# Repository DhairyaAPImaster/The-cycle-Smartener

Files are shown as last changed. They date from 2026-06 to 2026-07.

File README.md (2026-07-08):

Cycle smartener banner

# The Cycle Smartener
**(Makes the cycle kindda smart)**
### By Dhairya

## About "The Cycle Smartener"

So the Cycle smartener or TCS for short is basically this device that i designed that can be fitted on top of (almost) any modern cycle. Btw i made this cause i absolutelly love cycling and yeah having such a device would make the whole ride way more fun and interesting.

I plan on integrating TinyML (later) to also integrate AI into it so that it can do stuff like change the song or answer questions from voice commands. Alsoin next versions i plan on adding bluetooth so that one can connect their device - smart phone or something to it. and an sd card slot for one to put a micro sd in it to add music.

Btw it also has a 2.4inch LCD Display  (to displays whatever needs to be displayed).

## Folder Structure

`firmware/` - ESP32 firmware source code (C++)

`src/` - source files for PCB and CAD

`src/FreeCAD/` - mechanical CAD sources (open the .FCStd in FreeCAD)

`src/KiCAD/` - KiCad project files for the PCB

`Production/` - exports and fab outputs (gerbers, BOM, STLs)

`Production/PCB/` - gerbers, BOM, CPL files

`Production/CAD/` - exported STLs for the case

`images/` - screenshots and photos used in this README

## BOM with non PCB parts as well as PCB parts (with links)

Here's the parts list i kept while designing - both PCB parts and non-PCB components. i used the file `Production/BOM with non PCB parts too.csv` as the source.

| Item | Purpose | Qty | Unit Price (USD) | Total (USD) | Link |
| --- | --- | ---: | ---: | ---: | --- |
| Micro SD 16GB | For storage | 1 | $13.07 | $13.07 | [link](https://robu.in/product/sandisk-ultra-micro-sd-16gb-uhs-i-98mbs-r-class-10-memory-card/) |
| 40 Pin 2.54mm Male and Female Pin Headers | For connecting modules | 1 | $1.25 | $1.25 | [link](https://www.amazon.in/Super-Debug-Headers-Arduino-Prototype/dp/B09MZD3RBF) |
| Micro SD Card Reader Module | For storage/songs | 1 | $0.35 | $0.35 | [link](https://robu.in/product/micro-sd-card-module/) |
| 3mm Red LED | Status/Error Indicator | 11 | $0.01 | $0.10 | [link](https://robu.in/product/3mm-red-dip-led-pack-of-50/) |
| 3mm Green LED | Status/OK Indicator | 7 | $0.02 | $0.11 | [link](https://robu.in/product/5mm-green-surface-mount-led-pack-of-50/) |
| Tactile Push Button Switch 6x6 | Buttons | 1 Pack | $0.16 | $0.16 | [link](https://robu.in/product/6x6x5-tactile-push-button-switch/) |
| 10uF 25V Electrolytic Capacitor (Pack of 12) | Decoupling | 1 Pack | $0.83 | $0.83 | [link](https://www.amazon.in/10uF-25V-Electrolytic-Capacitor-Pack/dp/B08X2NSPZN) |
| 0.1µF Ceramic Capacitor (100nF) | Decoupling | 10 | $0.01 | $0.13 | [link](https://robu.in/product/100nf-50v-disc-capacitor/) |
| 150Ω Through-Hole Resistor | LED Current Limiting | 5 | $0.04 | $0.19 | [link](https://robu.in/product/mf25-150r-multicomp-pro-through-hole-resistor-150-ohm-mf25-series-250-mw-%C2%B1-1-axial-leaded-250-v/) |
| 10kΩ Through-Hole Resistor | Pull-up/Pull-down | 5 | $0.03 | $0.13 | [link](https://robu.in/product/mfr-25frf52-10k-yageo-metal-film-resistors-10k%CF%89-250mw-%C2%B1100ppm-%E2%84%83-%C2%B11-plugind2-4xl6-3mm-through-hole-resistors-rohs/) |
| 18650 Single Cell Holder | Battery Holder | 1 | $0.29 | $0.29 | [link](https://robu.in/product/1-x-18650-cell-box/) |
| 3.7V 2500mAh Li-Ion Battery | Power | 1 | $1.58 | $1.58 | [link](https://robocraze.com/products/3-7v-2500mah-18650-li-ion-battery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) |
| AMS1117-3.3V Voltage Regulator | Voltage Regulation | 2 | $0.09 | $0.19 | [link](https://robu.in/product/ams1117-3-3v-1a-sot-223-voltage-regulator-ic-pack-of-5-ics/) |
| TP4056 Type-C Charging Module | Li-Ion Charger | 1 | $0.17 | $0.17 | [link](https://robu.in/product/tp4056-1a-li-ion-battery-charging-board-micro-usb-with-current-protection-type-c-connector/) |
| INMP441 MEMS I2S Microphone Module | Audio Input | 1 | $4.58 | $4.58 | [link](https://www.flyrobo.in/inmp441-mems-high-precision-omnidirectional-microphone-module-i2s-interface-supports-esp32) |
| MAX98357 I2S 3W Class-D Audio Amplifier | Audio Output | 1 | $3.38 | $3.38 | [link](https://www.flyrobo.in/max98357-i2s-3w-class-d-audio-amplifier-module) |
| CP2102 USB to TTL UART Converter | Programming | 1 | $1.18 | $1.18 | [link](https://robu.in/product/cp-2102-6-pin/) |
| Waveshare 2.4" 240×320 LCD Display | User Interface | 1 | $11.09 | $11.09 | [link](https://robu.in/product/waveshare-240x320-general-2-4inch-lcd-display-module-65k-rgb/) |
| ESP32-WROOM-32U Wi-Fi + BLE Module | Main Microcontroller | 1 | $2.81 | $2.81 | [link](https://evelta.com/esp32-wroom-32u-wi-fi-ble-module-4mb-ipex-antenna-connector/?sku=136-ESP32-WROOM-32U-N4) |
| JLCPCB PCB Fabrication + Shipping | Custom PCB Manufacturing | 1 | $18.48 | $18.48 | [link](https://jlcpcb.com/) |
| JLCPCB Tax | Taxes | 1 | $7.40 | $7.40 | [link](https://jlcpcb.com/) |

| **Summary** | | | | |
| --- | --- | ---: | ---: | ---: |
| Electronics Components Total | | | | **$41.61** |
| JLCPCB (PCB + Shipping) | | | | **$18.48** |
| Tax | | | | **$7.40** |
| **Grand Total (USD)** | | | | **$67.49** |

***

## BOM with only PCB parts and no links (got from KiCAD)

<details>
<summary><b>Click to expand Bill of Materials</b></summary>

| Designator | Designation | Quantity | Footprint |
|---|---|---|---|
| C1, C2 | 10µF | 2 | CP_Radial_D5.0mm_P2.50mm |
| C3, C7, C8, C9 | 0.1uF | 4 | C_Disc_D5.0mm_W2.5mm_P5.00mm |
| C4 | 10uF | 1 | C_Disc_D5.0mm_W2.5mm_P5.00mm |
| D1 | GREEN LED | 1 | LED_D5.0mm |
| D2 | RED LED | 1 | LED_D5.0mm |
| J1 | TP4056 Module | 1 | PinHeader_1x02_P2.54mm_Vertical |
| J2 | AudioJack3 | 1 | Jack_3.5mm_CUI_SJ-3523-SMT_Horizontal |
| J3 | SD CARD READER | 1 | PinHeader_1x06_P2.54mm_Horizontal |
| J4 | J5A - INMP441 Left | 1 | PinHeader_1x03_P2.54mm_Vertical |
| J5 | J5B - INMP441 Right | 1 | PinHeader_1x06_P2.54mm_Vertical |
| J6 | UART_HEADER | 1 | PinHeader_1x08_P2.54mm_Vertical |
| J7 | Display connector | 1 | PinHeader_1x08_P2.54mm_Vertical |
| J8 | MAX 98357A_left | 1 | PinHeader_1x02_P2.54mm_Vertical |
| J9 | MAX 98357A_right | 1 | PinHeader_1x07_P2.54mm_Vertical |
| R1 | R | 1 | R_Axial_DIN0207_L6.3mm_D2.5mm_P10.16mm_Horizontal |
| R2 | 10k | 1 | R_Axial_DIN0207_L6.3mm_D2.5mm_P10.16mm_Horizontal |
| R4, R5 | 150 | 2 | R_Axial_DIN0207_L6.3mm_D2.5mm_P10.16mm_Horizontal |
| SW1, SW2 | SW_Push | 2 | SW_PUSH_6mm |
| U1 | ESP32-WROOM-32 | 1 | ESP32-WROOM-32 |
| U2 | AMS1117-3.3 | 1 | SOT-223-3_TabPin2 |

</details>

## How to Replicate

- Step 1 - Basically Just Clone or downlaod this repo from github. U can do this by either going to the code button on this repo page and pressing download Zip or u can clone this Repo Or you can go to the Releases on this repo and download the Zip File there too (the fastest way to download is like just going to code and pressing download Zip Or by cloning the Repo.)

- Step 2 - In the the production folder you will find the CAD and PCB folders.

- Step 3 - The CAD folder contains all the 3d Pritnable files for the case of the keyboard. If you wish to u can make any changes to the design or make your own design and use that instead.

- Step 4 - The PCB folder contains the Gerbers, BOM , and CPL files. These are the files that allow you to get the PCB manufactured from JLCPCB (im using JLCPCB) or any other PCB manufacturer(like PCBway or others).

- Step 5 - Upload the gerbers zip file in JLCPCB "Place order / get instant quote" Page (u will need to sign up to order but can get a quote without signing up)

- Step 6 - Change the colour of the PCB in the options JLC gives (if u use JLC PCB most of the times canging colours does not add any charge acc to what i know)

- Step 7 - Select PCBA if u want JLCPCB to assemble the PCB for you but ngl soldering all components by hand is cheaper and saves u a ton of money and also is pretty fun (im hand soldering all components)

- Step 8 - Upload the CPL and BOM files whe JLCPCB asks u to.

- Step 9 - Recheck the position of all components (i faced no problem with this as all components were in the correct place but i have faced issues with the placement in one of my other projects i made in KiCAD)
- Step 10 - Order the PCB

- Step 11 - if u dont have a 3d printer u can order the 3d model from JLC's JLC3DP but yeah all you have to do now is print the case and assemble the PCB in the case. (note u might have to trim down the spacers just a little)

- Step 12 - Get 8 M2 bolts and 8 heat insterts for it.

- Step 13 - Attatch the heat insrets into the case through the holes made for the hook. each hook has 4 holes for botlts.

- Step 14 - Position the hook from below on the cycles bar and position the case itself above it and then carefully screw in the screws securing the device to your cycle!!!!!!

- DONE!!!!! 

## Images











image (13)
image (12)
image (11)
image (11)
image (10)
image (10)
image (9)
image (9)
image (8)
image (8)
image (7)
image (7)
image (6)
image (6)
image (5)
image (5)
image (4)
image (4)
image (3)
image (3)
image (2)
image (2)
image (1)


## License and Credits

**License -->**
This project is licensed under the MIT License — see the [LICENSE](LICENSE) file for details.

**Credits -->**
***I used the following for making this project***

- ***KiCAD*** - For PCB design
- ***FreeCAD*** - For designing the Case
- **[APX HUB by @Gabouin](https://github.com/Gabouin/APX-USB-HUB)** - Readme template

## Final Notes

**Firmware Note --->  Used a friend help and also used AI (github copilot) too to like help me write a part of it as well ngl I suck at C++ also like used github copilot to like arrange the code in a more readable manner.**

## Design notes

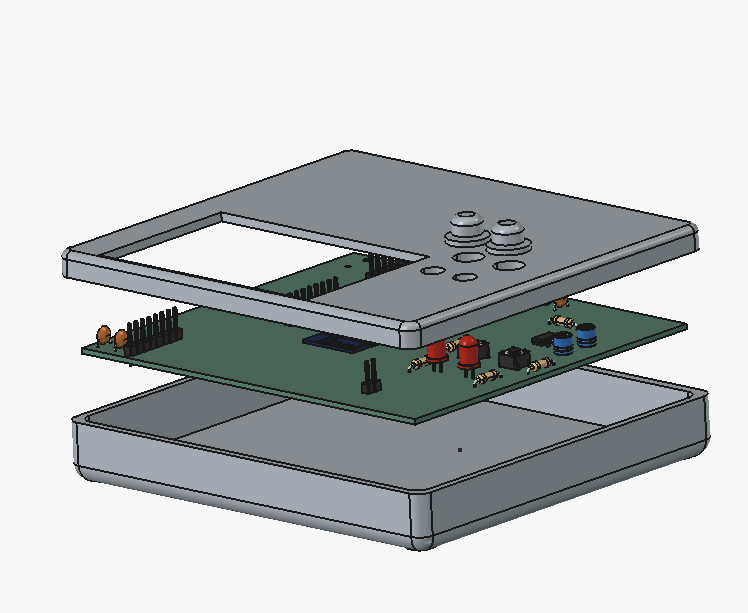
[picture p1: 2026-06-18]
images/Screenshot 2026-06-17 184801.png

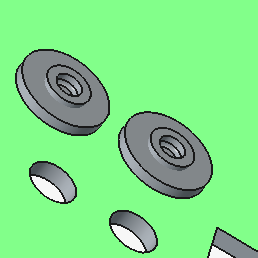
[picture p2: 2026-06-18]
images/Screenshot 2026-06-17 182813.png

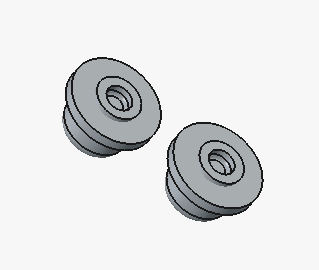
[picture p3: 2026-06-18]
images/Screenshot 2026-06-17 182823.png

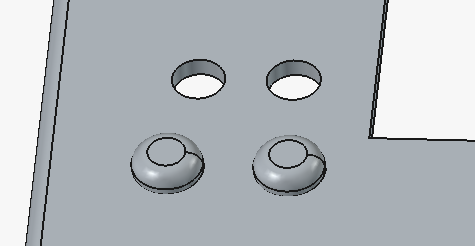
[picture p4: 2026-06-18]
images/Screenshot 2026-06-17 182800.png

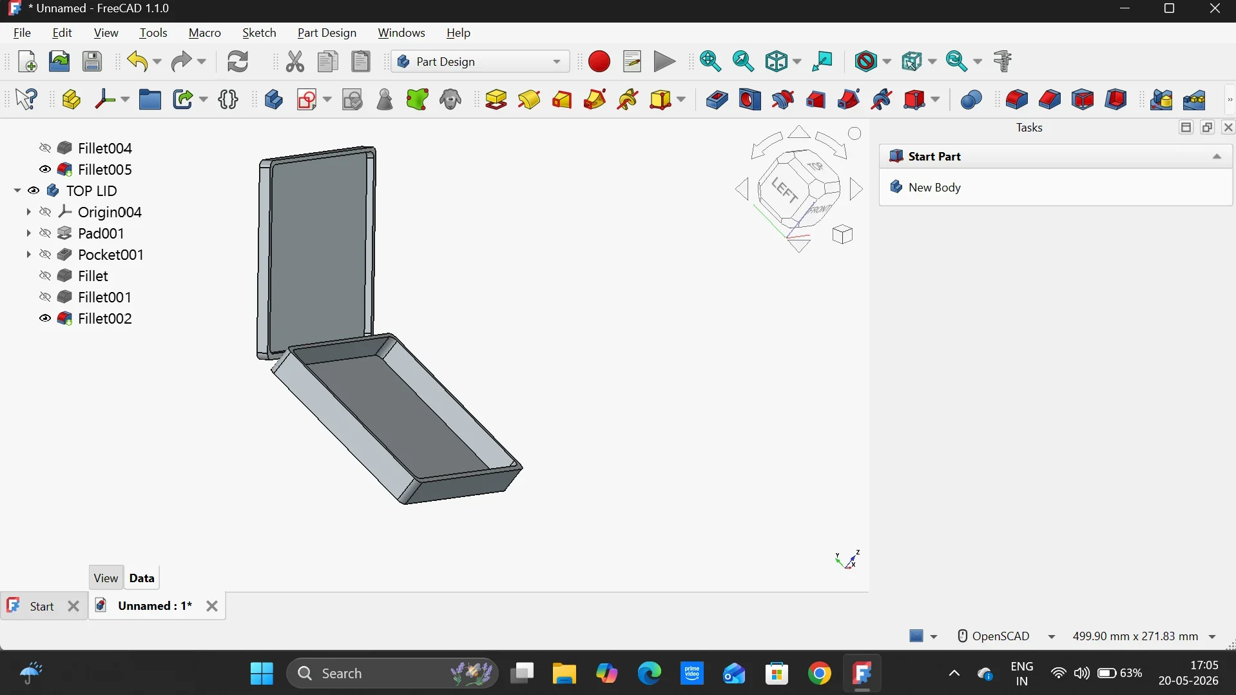
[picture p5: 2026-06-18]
images/image.webp

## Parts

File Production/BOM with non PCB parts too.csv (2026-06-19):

Name | Purpose | Quantity | Total Cost (USD) | Link | Distributor
Micro SD 16GB | For storage | 1 | 11.51 | https://robu.in/product/sandisk-ultra-micro-sd-16gb-uhs-i-98mbs-r-class-10-memory-card/ | Robu.in
40 Pin 2.54mm Male and Female Pin Headers | For connecting modules to the PCB. (btw this one has both male and female headers for almost the same price and umm... its good as i do not have to order both male and female headers separately and its also affordable with free delhivery.) | 1 | 1.78 | https://www.amazon.in/Super-Debug-Headers-Arduino-Prototype/dp/B09MZD3RBF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 | Amazon
Micro SD Card Reader Module | mainly for storage and adding songs | 1 | 0.34 | https://robu.in/product/micro-sd-card-module/ | Robu.in
3mm Red LED | to show that something is wrong in the PCB (robu.in has min order value of 10inr hence the qty is 7) | 7 | 0.11 | https://robu.in/product/3mm-red-dip-led-pack-of-50/ | Robu.in
3mm Green LED | to show that everything works (robu.in has min order value of 10inr hence the qty is 7) | 7 | 0.12 | https://robu.in/product/5mm-green-surface-mount-led-pack-of-50/ | Robu.in
Tactile Push Button Switch 6x6 | For the switches (btw robu.in has min order value of 10inr so instead of buying 10 individual buttons i got the pack of 10 at almost the same price) | 1 | 0.14 | http://robu.in/product/6x6x5-tactile-push-button-switch/ | Robu.in
10uF 25V Electrolytic Capacitor | For decoupling | 1 | 0.83 | https://www.amazon.in/10uF-25V-Electrolytic-Capacitor-Pack/dp/B08X2NSPZN?s=industrial | Amazon
0.1µF Ceramic Capacitor THT | For the decoupling capacitors(robu.in has min order value of 10inr so hence i had to put qty as 10) | 10 | 0.14 | https://robu.in/product/100nf-50v-disc-capacitor/ | Robu.in
150Ω Resistor THT | To resist at 150ohms | 5 | 0.20 | https://robu.in/product/mf25-150r-multicomp-pro-through-hole-resistor-150-ohm-mf25-series-250-mw-%C2%B1-1-axial-leaded-250-v/ | Robu.in
10kΩ Resistor THT | to "resist" the flow of current | 5 | 0.14 | https://robu.in/product/mfr-25frf52-10k-yageo-metal-film-resistors-10k%CF%89-250mw-%C2%B1100ppm-%E2%84%83-%C2%B11-plugind2-4xl6-3mm-through-hole-resistors-rohs/ | Robu.in
18650 single cell holder | To hold the battery | 1 | 0.31 | https://robu.in/product/1-x-18650-cell-box/ | Robu.in
3.7V 2600mAh Li-Ion Battery | to provide power. (1 battery is backup) | 2 | 2.70 | https://robu.in/product/dmegc-inr18650-26e-3-7v-2600mah-li-ion-battery/ | Robu.in
AMS1117 3.3V SOT223 | to regulate the voltage. btw robu.in has a minimum order value of 10inr hence i have to order 2 of these. | 2 | 0.19 | https://robu.in/product/ams1117-3-3v-1a-sot-223-voltage-regulator-ic-pack-of-5-ics/ | Robu.in
TP4056 micro USB charger module | To charge | 1 | 0.17 | https://robu.in/product/tp4056-1a-li-ion-battery-charging-board-micro-usb-with-current-protection-type-c-connector/ | Robu.in
INMP441 Mic Module | for microphone audio | 1 | 4.46 | https://www.flyrobo.in/inmp441-mems-high-precision-omnidirectional-microphone-module-i2s-interface-supports-esp32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 | FlyRobo
MAX98357 I2S 3W CLASS D Audio Amplifier Module | For audio to convert digital signals to analog while amplifying it. | 1 | 3.47 | https://www.flyrobo.in/max98357-i2s-3w-class-d-audio-amplifier-module?tracking=ads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 | FlyRobo
CP2102(6-pin) USB 2.0 to TTL UART serial converter | To program the esp32 wroom32 chip | 1 | 1.20 | http://robu.in/product/cp-2102-6-pin/ | robu.in
2.4inch LCD Display Module | To see | 1 | 10.95 | https://robu.in/product/waveshare-240x320-general-2-4inch-lcd-display-module-65k-rgb/ | Robu.in
ESP32-WROOM-32U Wi-Fi BLE Module | This is basically the brains of this project it shall run every component. | 1 | 3.29 | https://evelta.com/esp32-wroom-32u-wi-fi-ble-module-4mb-ipex-antenna-connector/?sku=136-ESP32-WROOM-32U-N4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 | Evelta

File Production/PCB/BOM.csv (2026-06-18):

Id | Designator | Footprint | Quantity | Designation | Supplier and ref
1 | C1, C2 | CP_Radial_D5.0mm_P2.50mm | 2 | 10µF
2 | C3, C7, C8, C9 | C_Disc_D5.0mm_W2.5mm_P5.00mm | 4 | 0.1uF
3 | C4 | C_Disc_D5.0mm_W2.5mm_P5.00mm | 1 | 10uF
4 | D1 | LED_D5.0mm | 1 | GREEN LED
5 | D2 | LED_D5.0mm | 1 | RED LED
6 | J1 | PinHeader_1x02_P2.54mm_Vertical | 1 | TP4056 Module
7 | J2 | Jack_3.5mm_CUI_SJ-3523-SMT_Horizontal | 1 | AudioJack3
8 | J3 | PinHeader_1x06_P2.54mm_Horizontal | 1 | SD CARD READER
9 | J4 | PinHeader_1x03_P2.54mm_Vertical | 1 | J5A - INMP441 Left
10 | J5 | PinHeader_1x06_P2.54mm_Vertical | 1 | J5B - INMP441 Right
11 | J6 | PinHeader_1x08_P2.54mm_Vertical | 1 | UART_HEADER
12 | J7 | PinHeader_1x08_P2.54mm_Vertical | 1 | Display connector
13 | J8 | PinHeader_1x02_P2.54mm_Vertical | 1 | MAX 98357A_left
14 | J9 | PinHeader_1x07_P2.54mm_Vertical | 1 | MAX 98357A_right
15 | R1 | R_Axial_DIN0207_L6.3mm_D2.5mm_P10.16mm_Horizontal | 1 | R
16 | R2 | R_Axial_DIN0207_L6.3mm_D2.5mm_P10.16mm_Horizontal | 1 | 10k
17 | R4, R5 | R_Axial_DIN0207_L6.3mm_D2.5mm_P10.16mm_Horizontal | 2 | 150
18 | SW1, SW2 | SW_PUSH_6mm | 2 | SW_Push
19 | U1 | ESP32-WROOM-32 | 1 | ESP32-WROOM-32
20 | U2 | SOT-223-3_TabPin2 | 1 | AMS1117-3.3

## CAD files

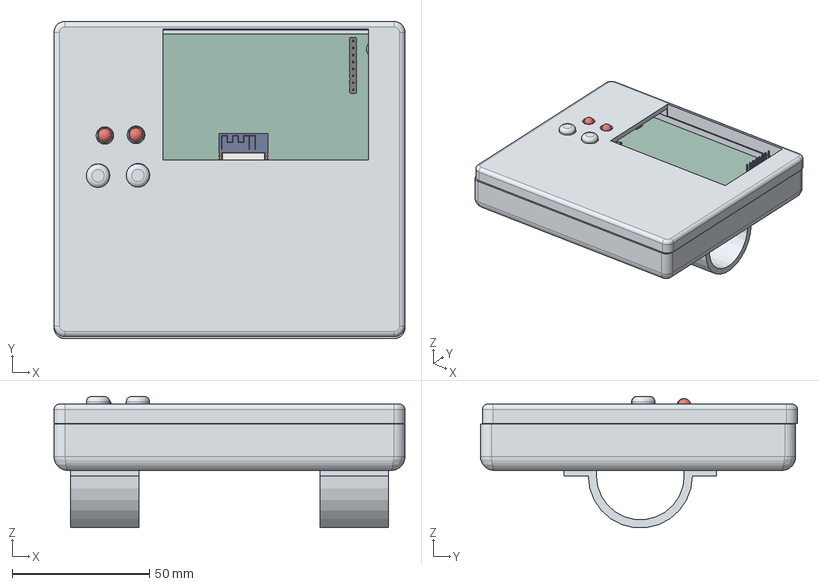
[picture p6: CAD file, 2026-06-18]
Assembly.step
128.0 x 115.7 x 47.9 mm
TOP LID
PCB
C_Disc_D5.0mm_W2.5mm_P5.00mm
PinHeader_1x07_P2.54mm_Vertical
C_Disc_D5.0mm_W2.5mm_P5.00mm001
PinHeader_1x08_P2.54mm_Vertical
PinHeader_1x08_P2.54mm_Vertical001
C_Disc_D5.0mm_W2.5mm_P5.00mm002
ESP32-WROOM-32
R_Axial_DIN0207_L6.3mm_D2.5mm_P10.16mm_Horizontal
C_Disc_D5.0mm_W2.5mm_P5.00mm003
C_Disc_D5.0mm_W2.5mm_P5.00mm004
CP_Radial_D5.0mm_P2.50mm
PinHeader_1x03_P2.54mm_Vertical
R_Axial_DIN0207_L6.3mm_D2.5mm_P10.16mm_Horizontal001
PinHeader_1x02_P2.54mm_Vertical
R_Axial_DIN0207_L6.3mm_D2.5mm_P10.16mm_Horizontal002
R_Axial_DIN0207_L6.3mm_D2.5mm_P10.16mm_Horizontal003
CP_Radial_D5.0mm_P2.50mm001
CP_Radial_D5.0mm_P2.50mm002
LED_D5.0mm
PinHeader_1x06_P2.54mm_Vertical
R_Axial_DIN0207_L6.3mm_D2.5mm_P10.16mm_Horizontal004
SW_PUSH_6mm
C_Disc_D5.0mm_W2.5mm_P5.00mm005
PinHeader_1x02_P2.54mm_Vertical001
LED_D5.0mm001
SW_PUSH_6mm001
SOT-223
PCB wired_PCB
Butons
button caps non slider plate disc
Cycle handle clamp
Cycle handle clamp001

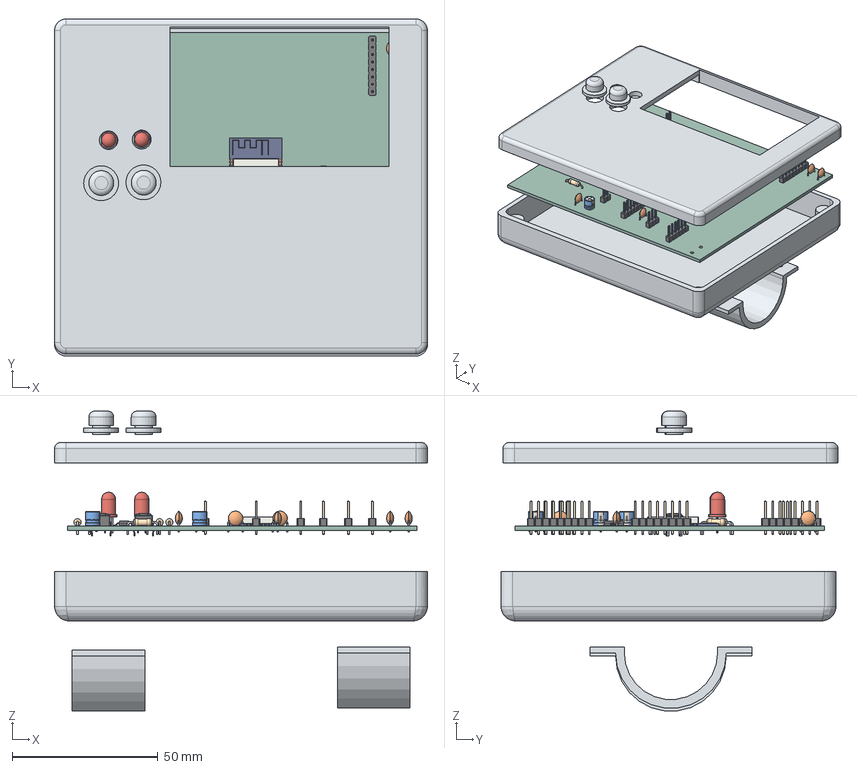
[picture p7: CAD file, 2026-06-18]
Assembly Layered.step
128.0 x 115.7 x 102.9 mm
TOP LID
PCB
C_Disc_D5.0mm_W2.5mm_P5.00mm
PinHeader_1x07_P2.54mm_Vertical
C_Disc_D5.0mm_W2.5mm_P5.00mm001
PinHeader_1x08_P2.54mm_Vertical
PinHeader_1x08_P2.54mm_Vertical001
C_Disc_D5.0mm_W2.5mm_P5.00mm002
ESP32-WROOM-32
R_Axial_DIN0207_L6.3mm_D2.5mm_P10.16mm_Horizontal
C_Disc_D5.0mm_W2.5mm_P5.00mm003
C_Disc_D5.0mm_W2.5mm_P5.00mm004
CP_Radial_D5.0mm_P2.50mm
PinHeader_1x03_P2.54mm_Vertical
R_Axial_DIN0207_L6.3mm_D2.5mm_P10.16mm_Horizontal001
PinHeader_1x02_P2.54mm_Vertical
R_Axial_DIN0207_L6.3mm_D2.5mm_P10.16mm_Horizontal002
R_Axial_DIN0207_L6.3mm_D2.5mm_P10.16mm_Horizontal003
CP_Radial_D5.0mm_P2.50mm001
CP_Radial_D5.0mm_P2.50mm002
LED_D5.0mm
PinHeader_1x06_P2.54mm_Vertical
R_Axial_DIN0207_L6.3mm_D2.5mm_P10.16mm_Horizontal004
SW_PUSH_6mm
C_Disc_D5.0mm_W2.5mm_P5.00mm005
PinHeader_1x02_P2.54mm_Vertical001
LED_D5.0mm001
SW_PUSH_6mm001
SOT-223
PCB wired_PCB
Butons
button caps non slider plate disc
Cycle handle clamp
Cycle handle clamp001

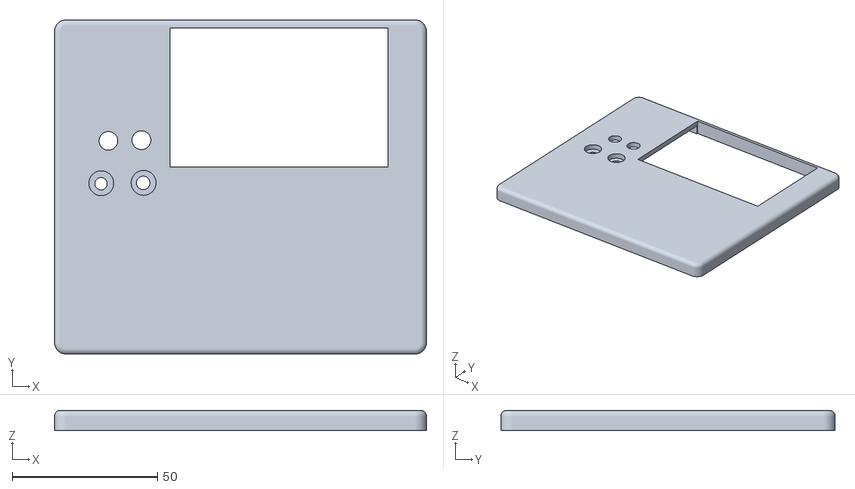
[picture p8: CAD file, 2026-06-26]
all 3d files in .stl format/Top Case.stl
128.0 x 115.0 x 7.00

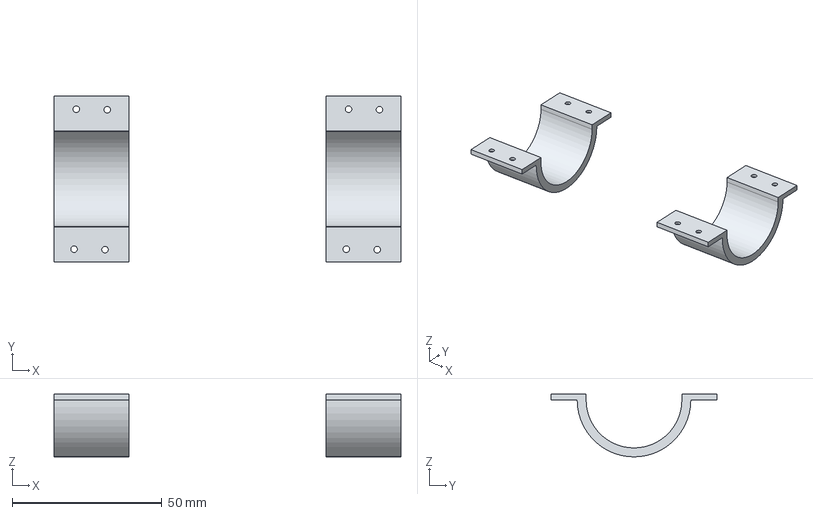
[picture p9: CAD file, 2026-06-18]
Production/CAD/Handle Clamps.step
116.0 x 55.6 x 21.0 mm
Cycle handle clamp
Cycle handle clamp001

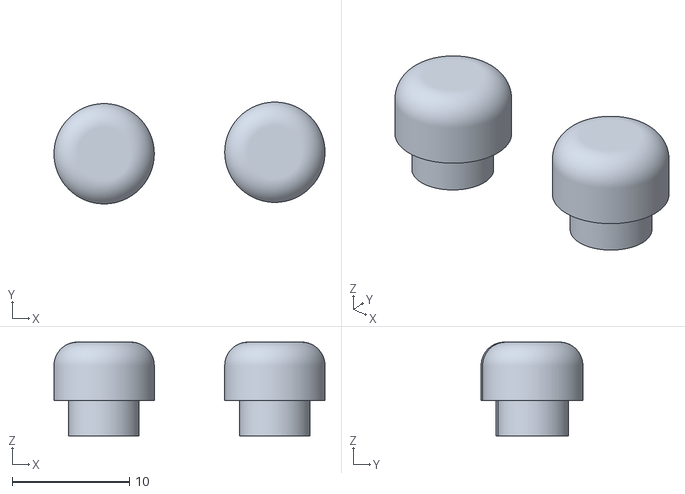
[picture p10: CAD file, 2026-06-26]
all 3d files in .stl format/Buttons.stl
23.1 x 8.68 x 8.00

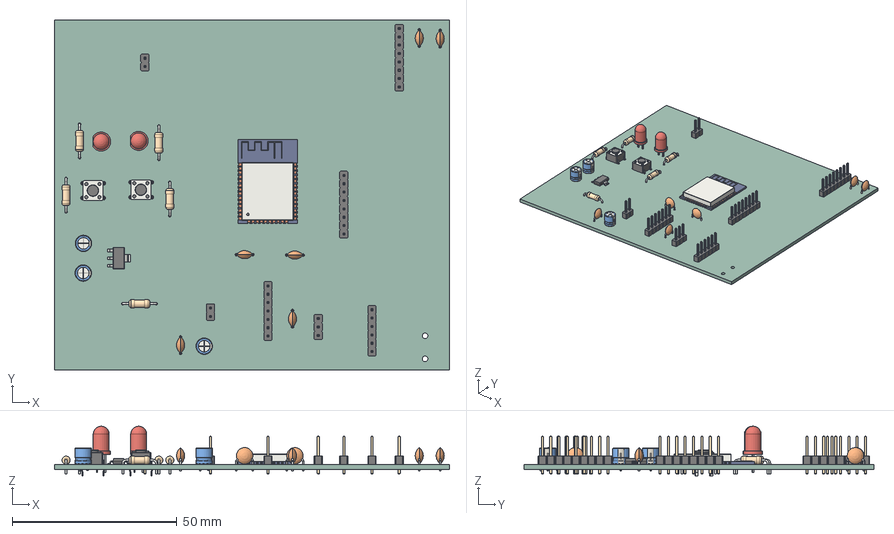
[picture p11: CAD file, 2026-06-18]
PCB 3d Model.step
120.0 x 106.3 x 15.1 mm
C_Disc_D5.0mm_W2.5mm_P5.00mm
PinHeader_1x07_P2.54mm_Vertical
C_Disc_D5.0mm_W2.5mm_P5.00mm001
PinHeader_1x08_P2.54mm_Vertical
PinHeader_1x08_P2.54mm_Vertical001
C_Disc_D5.0mm_W2.5mm_P5.00mm002
ESP32-WROOM-32
R_Axial_DIN0207_L6.3mm_D2.5mm_P10.16mm_Horizontal
C_Disc_D5.0mm_W2.5mm_P5.00mm003
C_Disc_D5.0mm_W2.5mm_P5.00mm004
CP_Radial_D5.0mm_P2.50mm
PinHeader_1x03_P2.54mm_Vertical
R_Axial_DIN0207_L6.3mm_D2.5mm_P10.16mm_Horizontal001
PinHeader_1x02_P2.54mm_Vertical
R_Axial_DIN0207_L6.3mm_D2.5mm_P10.16mm_Horizontal002
R_Axial_DIN0207_L6.3mm_D2.5mm_P10.16mm_Horizontal003
CP_Radial_D5.0mm_P2.50mm001
CP_Radial_D5.0mm_P2.50mm002
LED_D5.0mm
PinHeader_1x06_P2.54mm_Vertical
R_Axial_DIN0207_L6.3mm_D2.5mm_P10.16mm_Horizontal004
SW_PUSH_6mm
C_Disc_D5.0mm_W2.5mm_P5.00mm005
PinHeader_1x02_P2.54mm_Vertical001
LED_D5.0mm001
SW_PUSH_6mm001
SOT-223
PCB wired_PCB

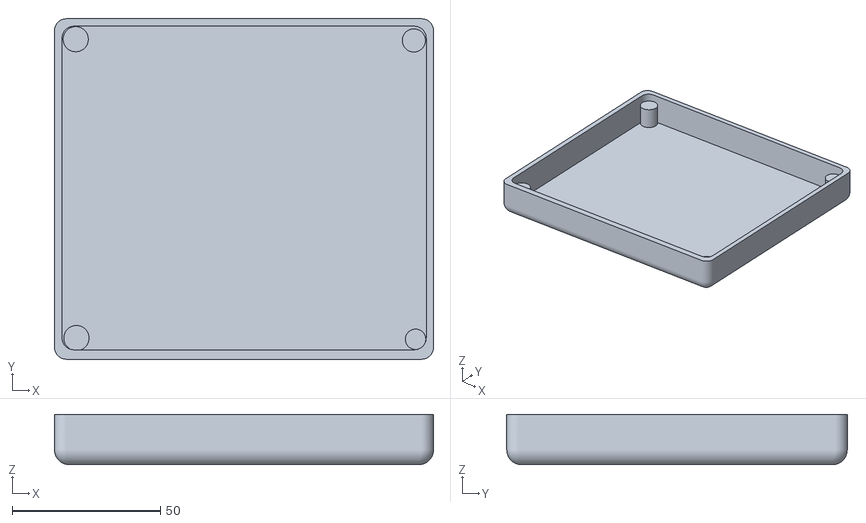
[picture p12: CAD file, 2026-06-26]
all 3d files in .stl format/Bottom Case.stl
128.0 x 115.0 x 17.0

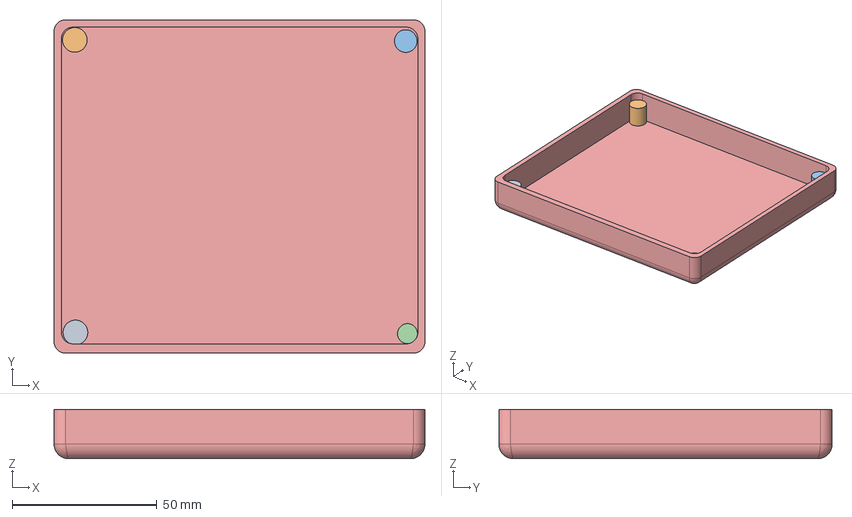
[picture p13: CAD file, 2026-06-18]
Production/CAD/Bottom Case.step
128.0 x 115.0 x 17.0 mm
PCB

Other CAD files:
src/FreeCAD/Case 3d Model.FCStd
Production/CAD/Buttons.step
all 3d files in .stl format/Handle Clamps.stl
Production/CAD/Top Case.step

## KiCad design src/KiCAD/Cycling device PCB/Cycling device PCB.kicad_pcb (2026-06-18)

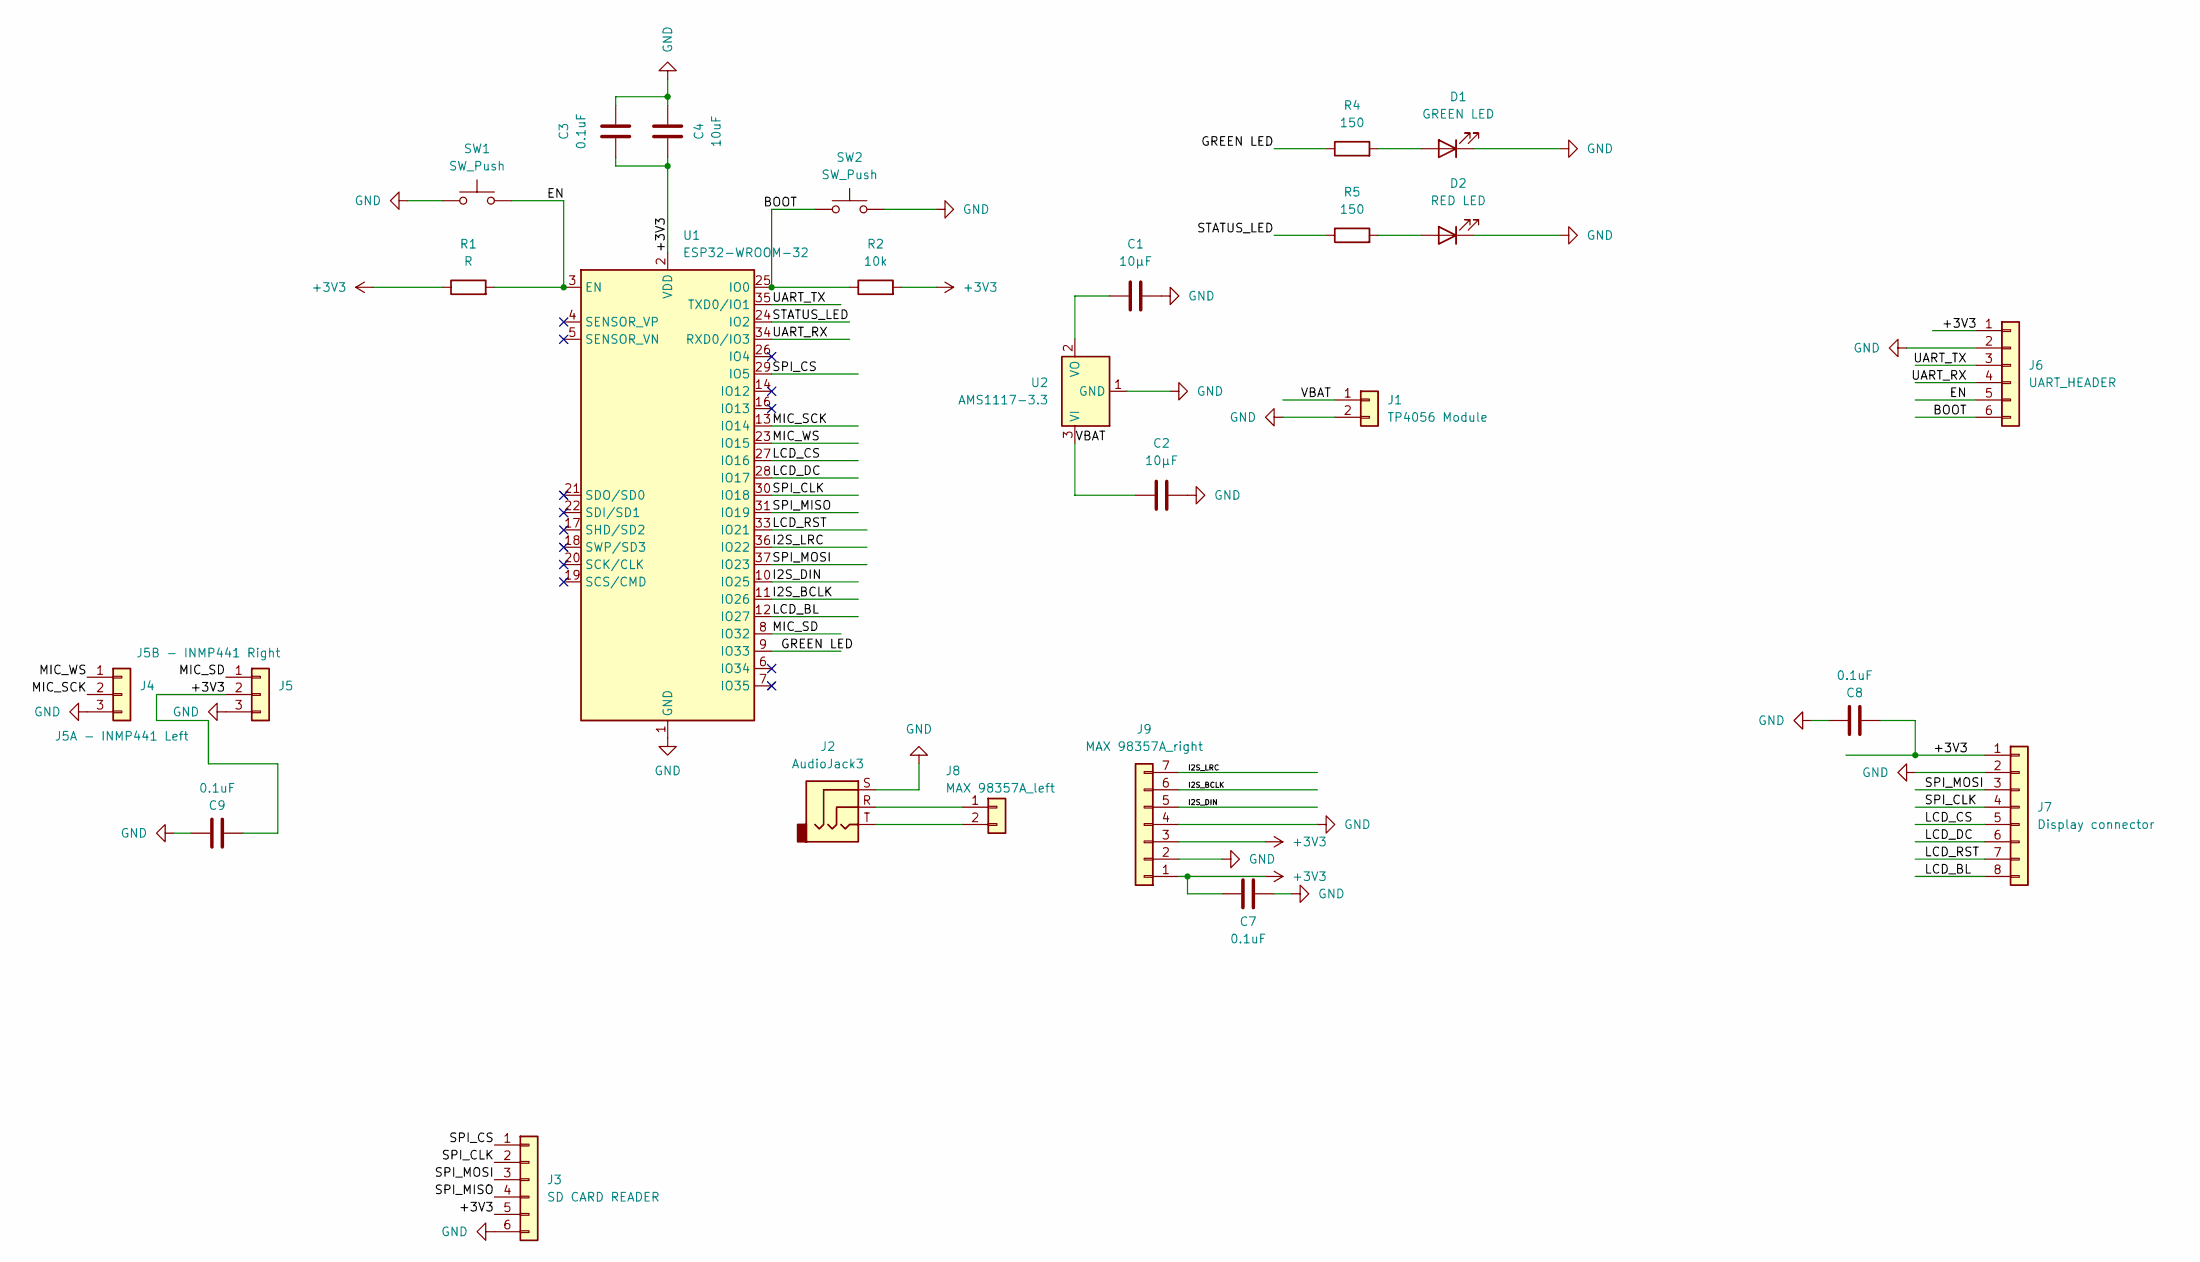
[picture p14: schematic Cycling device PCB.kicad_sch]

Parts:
C1, C2: 10µF; CP_Radial_D5.0mm_P2.50mm
C3, C7, C8, C9: 0.1uF; C_Disc_D5.0mm_W2.5mm_P5.00mm
C4: 10uF; C_Disc_D5.0mm_W2.5mm_P5.00mm
D1: GREEN LED; LED_D5.0mm
D2: RED LED; LED_D5.0mm
J1: TP4056 Module; PinHeader_1x02_P2.54mm_Vertical
J2: AudioJack3; Jack_3.5mm_CUI_SJ-3523-SMT_Horizontal
J3: SD CARD READER; PinHeader_1x06_P2.54mm_Horizontal
J4: J5A - INMP441 Left; PinHeader_1x03_P2.54mm_Vertical
J5: J5B - INMP441 Right; PinHeader_1x06_P2.54mm_Vertical
J6: UART_HEADER; PinHeader_1x08_P2.54mm_Vertical
J7: Display connector; PinHeader_1x08_P2.54mm_Vertical
J8: MAX 98357A_left; PinHeader_1x02_P2.54mm_Vertical
J9: MAX 98357A_right; PinHeader_1x07_P2.54mm_Vertical
R1: R; R_Axial_DIN0207_L6.3mm_D2.5mm_P10.16mm_Horizontal
R2: 10k; R_Axial_DIN0207_L6.3mm_D2.5mm_P10.16mm_Horizontal
R4, R5: 150; R_Axial_DIN0207_L6.3mm_D2.5mm_P10.16mm_Horizontal
SW1, SW2: SW_Push; SW_PUSH_6mm
U1: ESP32-WROOM-32
U2: AMS1117-3.3; SOT-223-3_TabPin2

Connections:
+3V3: C3.1, C4.1, C7.2, C8.2, C9.2, J3.5, J5.2, J6.1, J7.1, J9.1, J9.3, R1.1, R2.2, U1.2 (VDD)
/BOOT: J6.6, R2.1, SW2.1, U1.25 (IO0)
/EN: J6.5, R1.2, SW1.2, U1.3 (EN)
/GREEN LED: R4.1, U1.9 (IO33)
/I2S_BCLK: J9.6, U1.11 (IO26)
/I2S_DIN: J9.5, U1.10 (IO25)
/I2S_LRC: J9.7, U1.36 (IO22)
/LCD_BL: J7.8, U1.12 (IO27)
/LCD_CS: J7.5, U1.27 (IO16)
/LCD_DC: J7.6, U1.28 (IO17)
/LCD_RST: J7.7, U1.33 (IO21)
/MIC_SCK: J4.2, U1.13 (IO14)
/MIC_SD: J5.1, U1.8 (IO32)
/MIC_WS: J4.1, U1.23 (IO15)
/SPI_CLK: J3.2, J7.4, U1.30 (IO18)
/SPI_CS: J3.1, U1.29 (IO5)
/SPI_MISO: J3.4, U1.31 (IO19)
/SPI_MOSI: J3.3, J7.3, U1.37 (IO23)
/STATUS_LED: R5.1, U1.24 (IO2)
/UART_RX: J6.4, U1.34 (RXD0/IO3)
/UART_TX: J6.3, U1.35 (TXD0/IO1)
/VBAT: C2.1, J1.1, U2.3 (VI)
GND: C1.2, C2.2, C3.2, C4.2, C7.1, C8.1, C9.1, D1.1 (K), D2.1 (K), J1.2, J2.S, J3.6, J4.3, J5.3, J6.2, J7.2, J9.2, J9.4, SW1.1, SW2.2, U1.1 (GND), U1.15 (GND), U1.38 (GND), U1.39 (GND), U2.1 (GND)
unnamed: D1.2 (A), R4.2
unnamed: D2.2 (A), R5.2
unnamed: J2.R, J8.1
unnamed: J2.T, J8.2
unnamed: C1.1, U2.2 (VO)

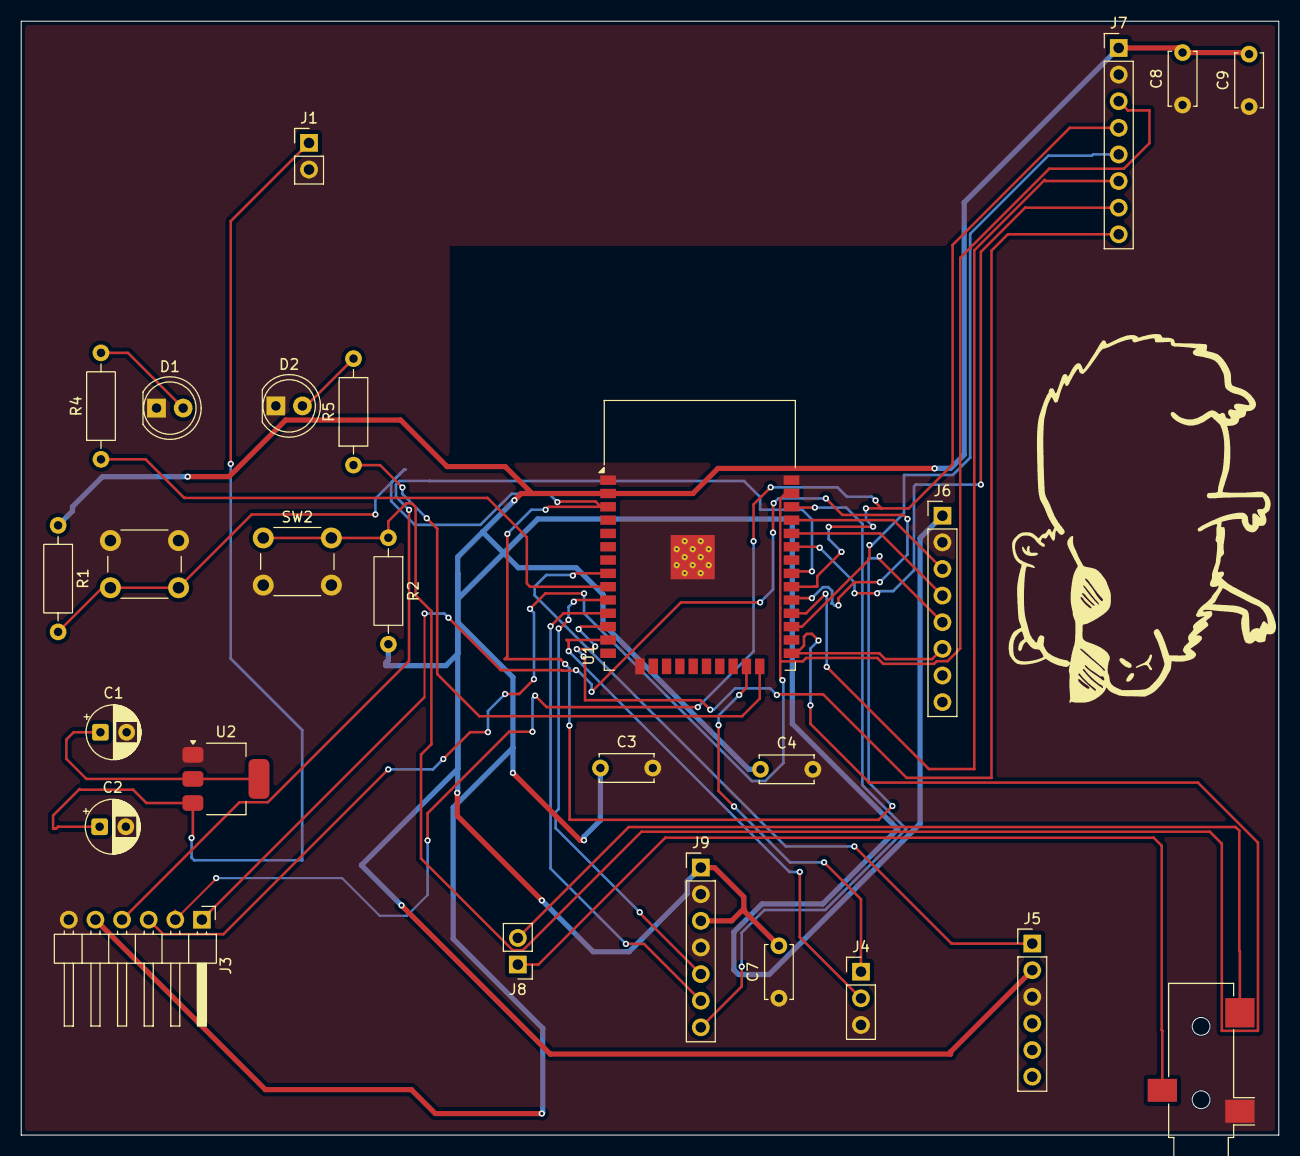
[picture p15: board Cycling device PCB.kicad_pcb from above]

Board: 2 copper layers, 120.0 x 106.3 mm, 26 parts (0 on the bottom side), 28 nets.

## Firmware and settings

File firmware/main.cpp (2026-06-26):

#include <Arduino.h>
#include <SPI.h>
#include <SD.h>
#include <driver/i2s.h>
#include <Preferences.h>
#include <Wire.h>

#if __has_include(<Adafruit_GFX.h>)
#include <Adafruit_GFX.h>
#include <Adafruit_ILI9341.h>
#define HAS_LCD_LIB 1
#else
#define HAS_LCD_LIB 0
#endif

namespace {
constexpr gpio_num_t PIN_SD_CS = GPIO_NUM_5;
constexpr gpio_num_t PIN_LCD_CS = GPIO_NUM_16;
constexpr gpio_num_t PIN_LCD_DC = GPIO_NUM_17;
constexpr gpio_num_t PIN_LCD_RST = GPIO_NUM_21;
constexpr gpio_num_t PIN_LCD_BL = GPIO_NUM_27;
constexpr gpio_num_t PIN_SPI_SCK = GPIO_NUM_18;
constexpr gpio_num_t PIN_SPI_MOSI = GPIO_NUM_23;
constexpr gpio_num_t PIN_SPI_MISO = GPIO_NUM_19;

constexpr gpio_num_t PIN_I2S_BCLK = GPIO_NUM_26;
constexpr gpio_num_t PIN_I2S_LRCLK = GPIO_NUM_22;
constexpr gpio_num_t PIN_I2S_DIN = GPIO_NUM_25;
constexpr gpio_num_t PIN_I2S_MIC_BCLK = GPIO_NUM_14;
constexpr gpio_num_t PIN_I2S_MIC_WS = GPIO_NUM_15;
constexpr gpio_num_t PIN_I2S_MIC_SD = GPIO_NUM_32;
constexpr gpio_num_t PIN_I2S_AMP_SD = GPIO_NUM_25;

constexpr gpio_num_t PIN_STATUS_LED = GPIO_NUM_2;
constexpr gpio_num_t PIN_BOOT_BUTTON = GPIO_NUM_0;
constexpr gpio_num_t PIN_BUTTON_1 = GPIO_NUM_34;
constexpr gpio_num_t PIN_BUTTON_2 = GPIO_NUM_35;

constexpr uint32_t AUDIO_SAMPLE_RATE = 16000;
constexpr size_t AUDIO_FRAME_COUNT = 256;

Preferences preferences;

#if HAS_LCD_LIB
Adafruit_ILI9341 lcd(PIN_LCD_CS, PIN_LCD_DC, PIN_LCD_RST);
#endif

bool sdReady = false;
bool lcdReady = false;

void setBacklight(bool enabled) {
  digitalWrite(static_cast<int>(PIN_LCD_BL), enabled ? HIGH : LOW);
}

void setStatusLed(bool enabled) {
  digitalWrite(static_cast<int>(PIN_STATUS_LED), enabled ? HIGH : LOW);
}

void drawBootScreen(const char *line1, const char *line2, uint16_t color) {
#if HAS_LCD_LIB
  if (!lcdReady) {
    return;
  }
  lcd.fillScreen(ST77XX_BLACK);
  lcd.setTextWrap(true);
  lcd.setTextSize(2);
  lcd.setTextColor(color);
  lcd.setCursor(12, 24);
  lcd.println(line1);
  lcd.setCursor(12, 64);
  lcd.setTextSize(1);
  lcd.println(line2);
#else
  (void)line1;
  (void)line2;
  (void)color;
#endif
}

void initDisplay() {
  pinMode(static_cast<int>(PIN_LCD_BL), OUTPUT);
  setBacklight(true);

#if HAS_LCD_LIB
  pinMode(static_cast<int>(PIN_LCD_CS), OUTPUT);
  pinMode(static_cast<int>(PIN_LCD_DC), OUTPUT);
  pinMode(static_cast<int>(PIN_LCD_RST), OUTPUT);
  SPI.begin(static_cast<uint8_t>(PIN_SPI_SCK), static_cast<uint8_t>(PIN_SPI_MISO), static_cast<uint8_t>(PIN_SPI_MOSI), static_cast<uint8_t>(PIN_LCD_CS));
  lcd.begin();
  lcd.setRotation(1);
  lcdReady = true;
  drawBootScreen("Cycle Smartener", "LCD ready", ST77XX_GREEN);
#else
  lcdReady = false;
#endif
}

void initSdCard() {
  SPI.begin(static_cast<uint8_t>(PIN_SPI_SCK), static_cast<uint8_t>(PIN_SPI_MISO), static_cast<uint8_t>(PIN_SPI_MOSI), static_cast<uint8_t>(PIN_SD_CS));
  pinMode(static_cast<int>(PIN_SD_CS), OUTPUT);
  digitalWrite(static_cast<int>(PIN_SD_CS), HIGH);

  sdReady = SD.begin(static_cast<uint8_t>(PIN_SD_CS), SPI, 20000000);
  if (sdReady) {
    Serial.println("SD card mounted");
  } else {
    Serial.println("SD card mount failed");
  }
}

bool initAudioOutput() {
  const i2s_config_t config = {
      .mode = static_cast<i2s_mode_t>(I2S_MODE_MASTER | I2S_MODE_TX),
      .sample_rate = static_cast<int>(AUDIO_SAMPLE_RATE),
      .bits_per_sample = I2S_BITS_PER_SAMPLE_16BIT,
      .channel_format = I2S_CHANNEL_FMT_RIGHT_LEFT,
      .communication_format = I2S_COMM_FORMAT_STAND_I2S,
      .intr_alloc_flags = ESP_INTR_FLAG_LEVEL1,
      .dma_buf_count = 8,
      .dma_buf_len = 256,
      .use_apll = false,
      .tx_desc_auto_clear = true,
      .fixed_mclk = 0,
  };

  const i2s_pin_config_t pins = {
      .bck_io_num = static_cast<int>(PIN_I2S_BCLK),
      .ws_io_num = static_cast<int>(PIN_I2S_LRCLK),
      .data_out_num = static_cast<int>(PIN_I2S_DIN),
      .data_in_num = I2S_PIN_NO_CHANGE,
  };

  if (i2s_driver_install(I2S_NUM_0, &config, 0, nullptr) != ESP_OK) {
    return false;
  }
  if (i2s_set_pin(I2S_NUM_0, &pins) != ESP_OK) {
    return false;
  }
  return true;
}

bool initMicInput() {
  const i2s_config_t config = {
      .mode = static_cast<i2s_mode_t>(I2S_MODE_MASTER | I2S_MODE_RX),
      .sample_rate = static_cast<int>(AUDIO_SAMPLE_RATE),
      .bits_per_sample = I2S_BITS_PER_SAMPLE_32BIT,
      .channel_format = I2S_CHANNEL_FMT_ONLY_LEFT,
      .communication_format = I2S_COMM_FORMAT_STAND_I2S,
      .intr_alloc_flags = ESP_INTR_FLAG_LEVEL1,
      .dma_buf_count = 8,
      .dma_buf_len = 256,
      .use_apll = false,
      .tx_desc_auto_clear = false,
      .fixed_mclk = 0,
  };

  const i2s_pin_config_t pins = {
      .bck_io_num = static_cast<int>(PIN_I2S_MIC_BCLK),
      .ws_io_num = static_cast<int>(PIN_I2S_MIC_WS),
      .data_out_num = I2S_PIN_NO_CHANGE,
      .data_in_num = static_cast<int>(PIN_I2S_MIC_SD),
  };

  if (i2s_driver_install(I2S_NUM_1, &config, 0, nullptr) != ESP_OK) {
    return false;
  }
  if (i2s_set_pin(I2S_NUM_1, &pins) != ESP_OK) {
    return false;
  }
  return true;
}

void showStorageSummary() {
#if HAS_LCD_LIB
  if (!lcdReady) {
    return;
  }
  lcd.fillScreen(ST77XX_BLACK);
  lcd.setCursor(0, 0);
  lcd.setTextSize(2);
  lcd.setTextColor(ST77XX_CYAN);
  lcd.println("Cycle Smartener");
  lcd.setTextSize(1);
  lcd.setTextColor(ST77XX_WHITE);
  lcd.print("SD: ");
  lcd.println(sdReady ? "ready" : "missing");
  lcd.print("Audio: ");
  lcd.println("I2S active");
  lcd.print("Buttons: ");
  lcd.println("boot / user");
#endif
}

void readButtons() {
  const bool bootPressed = digitalRead(static_cast<int>(PIN_BOOT_BUTTON)) == LOW;
  const bool button1Pressed = digitalRead(static_cast<int>(PIN_BUTTON_1)) == LOW;
  const bool button2Pressed = digitalRead(static_cast<int>(PIN_BUTTON_2)) == LOW;

  if (bootPressed) {
    setStatusLed(true);
  } else {
    setStatusLed(false);
  }

  if (button1Pressed) {
    preferences.putUInt("lastButton", 1);
  }
  if (button2Pressed) {
    preferences.putUInt("lastButton", 2);
  }
}

void readMicLevel() {
  static int32_t samples[AUDIO_FRAME_COUNT];
  size_t bytesRead = 0;
  esp_err_t result = i2s_read(I2S_NUM_1, samples, sizeof(samples), &bytesRead, 0);
  if (result != ESP_OK || bytesRead == 0) {
    return;
  }

  const size_t sampleCount = bytesRead / sizeof(int32_t);
  int64_t sum = 0;
  for (size_t index = 0; index < sampleCount; ++index) {
    sum += abs(samples[index] >> 14);
  }
  const uint32_t level = sampleCount ? static_cast<uint32_t>(sum / static_cast<int64_t>(sampleCount)) : 0;
  preferences.putUInt("micLevel", level);
}

void logSystemState() {
  Serial.printf("SD=%s LCD=%s Mic=%s\n", sdReady ? "ready" : "missing", lcdReady ? "ready" : "missing", "ready");
}
}  // namespace

void setup() {
  Serial.begin(115200);
  delay(200);

  pinMode(static_cast<int>(PIN_STATUS_LED), OUTPUT);
  pinMode(static_cast<int>(PIN_BOOT_BUTTON), INPUT_PULLUP);
  pinMode(static_cast<int>(PIN_BUTTON_1), INPUT);
  pinMode(static_cast<int>(PIN_BUTTON_2), INPUT);

  preferences.begin("cycle", false);

  initDisplay();
  initSdCard();

  const bool micReady = initMicInput();
  const bool ampReady = initAudioOutput();

  Serial.printf("Mic init: %s\n", micReady ? "ok" : "failed");
  Serial.printf("Amp init: %s\n", ampReady ? "ok" : "failed");

  showStorageSummary();
  logSystemState();
}

void loop() {
  static uint32_t lastUiRefresh = 0;
  static uint32_t lastMicRead = 0;

  readButtons();

  const uint32_t now = millis();
  if (now - lastMicRead >= 40) {
    lastMicRead = now;
    readMicLevel();
  }

  if (now - lastUiRefresh >= 1000) {
    lastUiRefresh = now;
    showStorageSummary();
    logSystemState();
  }

  delay(5);
}

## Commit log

2026-06-18 added the CAD production files
    [Assembly Layered.step, Assembly.step, Buttons.step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]
2026-06-18 renamed a folder
    [Bottom Case.step]
2026-06-18 designed the handle clamps to attatch to cycle and also updated the CAD files
    [Assembly Layered.step, Assembly.step, Case 3d Model.FCStd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]
2026-06-19 Almost finished the full readme
    Added folder structure, BOM, replication steps, images, and credits sections to README.
2026-06-19 added collapsable and tabular BOM in the Readme.
2026-06-19 aded a new BOM with all links and also all the non PCB components
    [BOM with non PCB parts too.csv]
2026-06-26 added the .stl files in a folder specifically made for the stl files. also added the C++ firmware code
    [Bottom Case.stl, Buttons.stl, Handle Clamps.stl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]
2026-07-08 Revise BOM format with pricing details
    Updated the BOM to include unit prices and total costs for components.
